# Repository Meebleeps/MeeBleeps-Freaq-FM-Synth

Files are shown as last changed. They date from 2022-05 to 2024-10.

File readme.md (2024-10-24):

# Meebleeps / Wirehead Freaq FM Synth
## Arduino Synth with Dual-voice 2-OP FM | Generative 2-track Polymetric Sequencer | Mozzi SDK

## NOTE This code is an open-source prototype and is not compatible with the Wirehead Instruments version of Freaq FM hardware
- Meebleeps was my personal project and was rebranded as Wirehead Instruments in 2023 to avoid brand confusion with MeeBlip - another completely separate synth design company.

An evolution of my first Mozzi synth build, this one features dual independent 2-operator FM voices paired with a 2-track generative sequencer.  

Each voice has independent carrier & modulator waveforms, FM ratio, modulation envelope & LFO.

Both tracks share the a single pattern (inspired by the Intellijel Metropolix) and can be stacked in unison or have different polymetric step-counts.  Track 1 can be offset 0-3 octaves above track 2 for separate bass & lead.

It started simple... but ended up cramming the 32K flash to the brim with features and wavetables, maxxing out the interface with obscure button combinations, and pushing the 16Mhz Arduino Nano to the edge!  Upside is it makes lots of funky noises now!

 #### Source Code:      https://github.com/Meebleeps/MeeBleeps-Freaq-FM-Synth
 #### Youtube Demo:     https://www.youtube.com/watch?v=KD6IrcmMkoA
 #### Youtube Channel:  https://www.youtube.com/channel/UC4I1ExnOpH_GjNtm7ZdWeWA

Source released under Creative Commons Attribution-NonCommercial-ShareAlike 4.0
Copyright (C) 2022 Meebleeps

***

## Important build-notes 

- My builds have used normally-closed switches, so the code assumes this.  09 May 2022: Added complier switches to handle normally-open switches
- This will probably compile to Arduino Uno, but it won't work properly without extensive modification as it uses all 8 of the Nano's analog input pins
- If you have issues with the compiled size not fitting in the Nano, this may be due to different compiler (I use VSCode & PlatformIO) or different bootloader in the Arduino (not sure which I have, but am compiling to Elegoo brand arduino nano). 
  - Check the compiler options in **MutantFMSynthOptions.h** to alter switch type or compile size
  - open the file MutantFMSynthOptions.h
  - find the line: `//#define COMPILE_SMALLER_BINARY`
  - uncomment the line so it looks like this:  `#define COMPILE_SMALLER_BINARY`
  - Then compile. It should now easily fit into the Nano.  This omits the semi-random wave tablesbut you probably won't miss it! :)
- Do not install the Mozzi library from PlatformIO in VSCode, it's outdated and will not build successfully. Instead, install its [latest git master branch](https://github.com/sensorium/Mozzi) to `lib/mozzi`. 
- The default settings target the Nano ATmega328 with the new bootloader. If you have avrdude errors during upload, you might have the old bootloader: change both instances of `nanoatmega328new` to `nanoatmega328` in `plaformio.ini`.

***

## Voices

-   2 independent FM voices
-   2-operator FM (for old-school prince of persia vibes! 😂)
-   Multi-mode FM ratios - quantised, free-multiple, independent
-   Multiple operator waveforms for carrier & modulator - Sine, Saw, Reverse Saw, Square, Noise, Off
-   Modulation level controlled by Attack/Decay envelope and LFO per-voice
-   Multiple LFO waveforms (same tables as the carrier oscillators) Sine, Saw, Reverse Saw, Square, Noise

## Sequencer

-   2/1.5 track polymetric sequencer with up to 16 steps per track (Both tracks use same note sequence but can have different step-counts for polymetric phasing)
-   Multiple generative algorithms - (semi)random notes, (semi)random runs, arpeggio, drone 
-   Sequence mutates/evolves at user-defined rate & note-density
-   Selectable tonic, octave & scale quantisation (Major, Minor, Pentatonic, Phrygian (GOA!), Octaves, Fifths)
-   Tap-tempo control
-   Sync input & output (Korg Volca compatible) 
-   16-step parameter-lock recording of synth parameters for track 1 (the Elektron way!)

## Hardware 
-   Arduino Nano (Elegoo) 
-   8x8 LED display with a MAX7219-based control board
-   Simple Mozzi output circuit 
-   Added power filtering caps on DC input and 5V rail
-   Designed to fit into Volca form factor 
-   Laser-cut metalisized acrylic faceplate 
-   Laser-cut wooden enclosure 
-   7V-12DC DC Power input 
-   Access to nano's USB port for firmware upgrades 

## Pins

These are the defaults defined for the faceplate controls:

| Pin | Function | Name in `MutantFMSynth.ino` |
|-----|---|---|
| A0  | Mutation | ANALOG_INPUT_MUTATION 
| A1  | Wobble | ANALOG_INPUT_LFO
| A2  | Population | ANALOG_INPUT_STEPCOUNT
| A3  | Attack | ANALOG_INPUT_MOD_ENVELOPE2 
| A4  | Lifespan | ANALOG_INPUT_DECAY
| A5  | Decay | ANALOG_INPUT_MOD_ENVELOPE1
| A6  | Ratio | ANALOG_INPUT_MOD_RATIO
| A7  | Depth | ANALOG_INPUT_MOD_AMOUNT 
| D3  | Start | BUTTON_INPUT_START
| D4  | Voice | BUTTON_INPUT_VOICE
| D5  | Rec | BUTTON_INPUT_REC
| D6  | Scales | BUTTON_INPUT_SCALE
| D10 | Func | BUTTON_INPUT_FUNC
| D12 | Tonic | BUTTON_INPUT_TONIC

## User Guide

### Buttons

-   Tonic - Select tonic through natural notes A - G
    -   [Func] + Tonic - Shift base octave from 0 - 5
    -   [Func][Rec] + Tonic - Select octave offset to Track 1 (track 1 & 2 can be 0-4 octaves apart)
-   Scales - Select current musical scale
    -   [Func] + Scales - Select current generative algorithm
    -   [Func][Rec] + Scales - Select the LFO waveform for the current voice 
-   Rec + knob - Hold down while moving a knob to record those parameters to the sequence 
    -   [Func][Rec] + knob - Hold down while moving a knob to delete the recorded sequence for that parameter 
    -   [Func][Rec] + buttons - Access various secondary functions
-   Start - Start or stop the sequencer
    -   [Func] + Start - Tap tempo
    -   [Func][Rec] + Start - Select the MODULATOR waveform for the current voice 
-   Voice - Select the active track which can be edited using the parameter inputs
    -   [Func] + Voice - Select the FM ratio mode for the current voice
    -   [Func][Rec] + Voice - Select CARRIER Waveform for the current voice 

### Rotary Inputs

-   Mutation - Adjust the likelihood that the sequence will change over time
    -   [Func] + Mutation - Adjust the liklihood that any given step will be a note or a rest
-   Population - Adjust the number of steps for the active track
    -   [Func] + Population - Adjust the number of steps for all tracks
-   Lifespan - Adjust the length of the notes (for all tracks)
-   Ratio - Select the carrier--to-modulator FM ratio (based on the current FM mode)
-   Wobble - Adjust the amount of LFO to apply to the modulator level for the active track
    -   [Func] + Wobble - Adjust the LFO rate for the active track
-   Attack - Adjust the attack time for the modulator level envelope
-   Decay - Adjust the decay time for the modulator level envelope
-   Depth - Adjust the amount of envelope to apply to the modulator level for the active track

## Issues / Limitations

-   Fair bit of jitter in the sequencer timing when tracking external sync due to somewhat naive approach to the 2-step-per-pulse volca sync 
-   Mozzi audio library has 10ms buffer 
-   The code is written for NORMALLY CLOSED switches - see latest updates in MutantFMSynth.ino updateButtonControls() for support for NORMALLY OPEN
-   The code may not fit in the Arduino Nano when compiled using the Arduino IDE or using different bootloaders

### Compiling on the Arduino IDE

If you have issues with the compiled size not fitting in the Nano, this may be due to different compiler (I use VSCode & PlatformIO) or different bootloader in the Arduino (not sure which I have, but am compiling to Elegoo brand arduino nano). 
- Check the compiler options in **MutantFMSynthOptions.h** to alter switch type or compile size
- open the file MutantFMSynthOptions.h
- find the line: //#define COMPILE_SMALLER_BINARY
- uncomment the line so it looks like this:  #define COMPILE_SMALLER_BINARY
- Then compile. It should now easily fit into the Nano.  This omits the semi-random wave tablesbut you probably won't miss it! :)

### Compiling in VSCode / PlatformIO

- Do not install the Mozzi library from PlatformIO in VSCode, it's outdated and will not build successfully. Instead, install its [latest git master branch](https://github.com/sensorium/Mozzi) to `lib/mozzi`. 
- The default settings target the Nano ATmega328 with the new bootloader. If you have avrdude errors during upload, you might have the old bootloader: change both instances of `nanoatmega328new` to `nanoatmega328` in `plaformio.ini`.

## Thanks

-   Inspired by Hagiwo's modular builds: https://www.youtube.com/channel/UCxErrnnVNEAAXPZvQFwobQw 
-   Mozzi audio library: https://sensorium.github.io/Mozzi/ 
-   Inkscape for vector graphics: https://inkscape.org/ 
-   Laser-cutting by Perth Creative Industries https://www.pcilasercutting.com.au/
-   Fritzing for circuit design: https://fritzing.org/ 
-   Great Scott for electronics tips! https://www.youtube.com/channel/UC6mIxFTvXkWQVEHPsEdflzQ

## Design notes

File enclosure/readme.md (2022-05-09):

Added awesome 3D printed enclosure files created by https://www.reddit.com/user/PollutionExpensive43/ - THANKS!

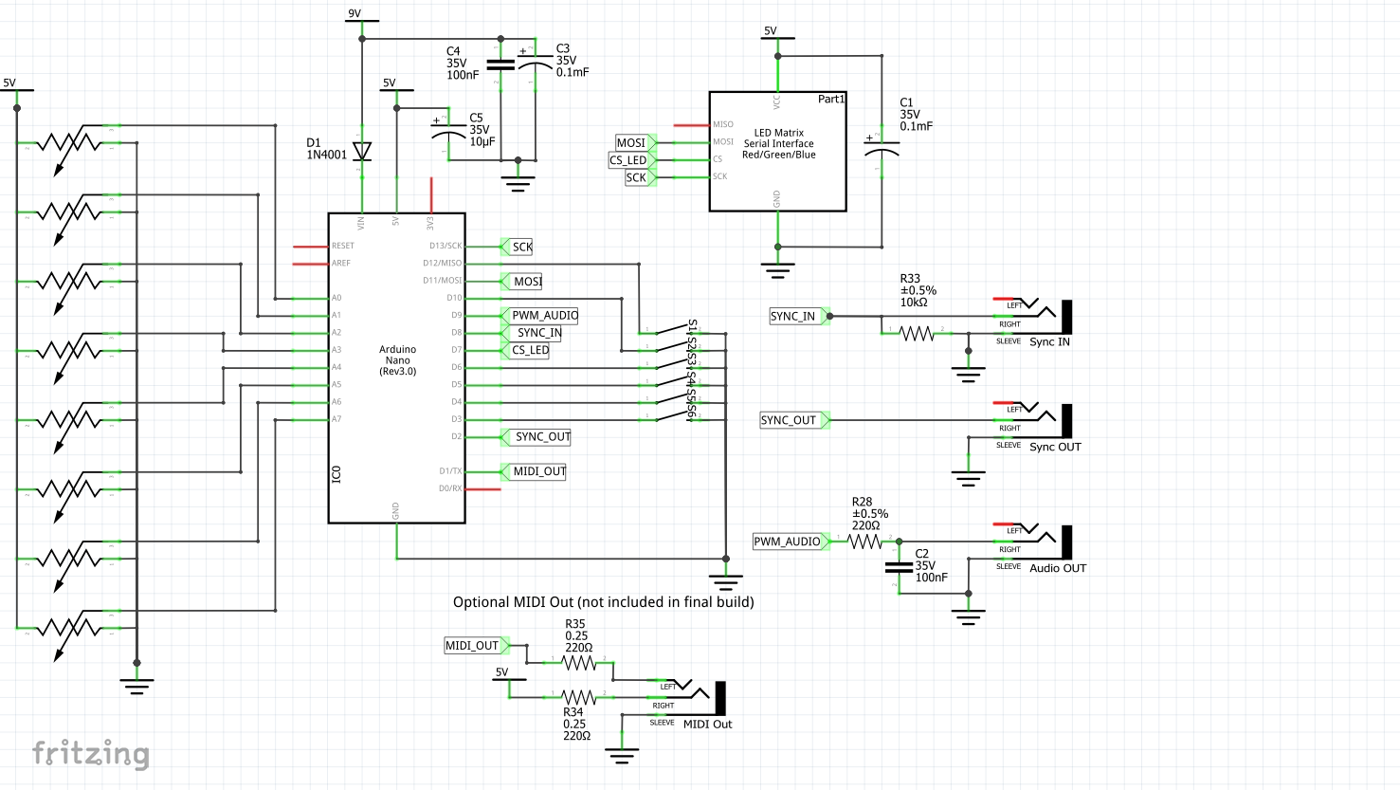
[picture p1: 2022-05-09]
MeeBleeps Freaq Schematic 26032022.png

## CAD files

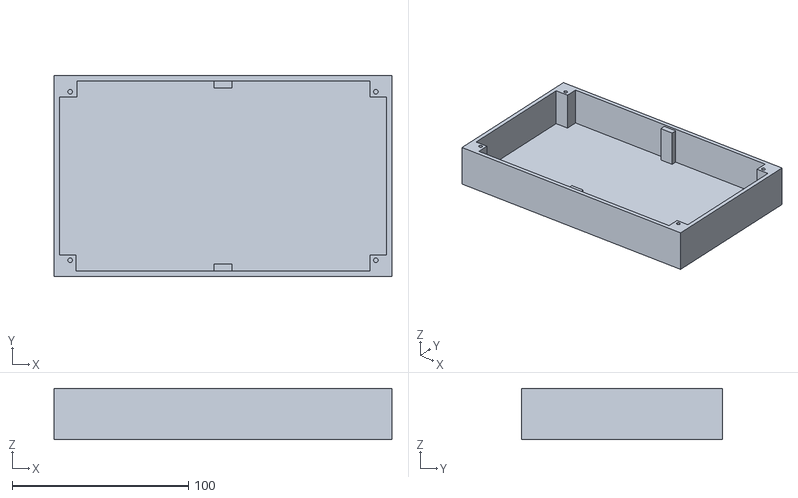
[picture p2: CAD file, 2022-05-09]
enclosure/Freaq Volca Case.stl
192.0 x 114.0 x 29.2

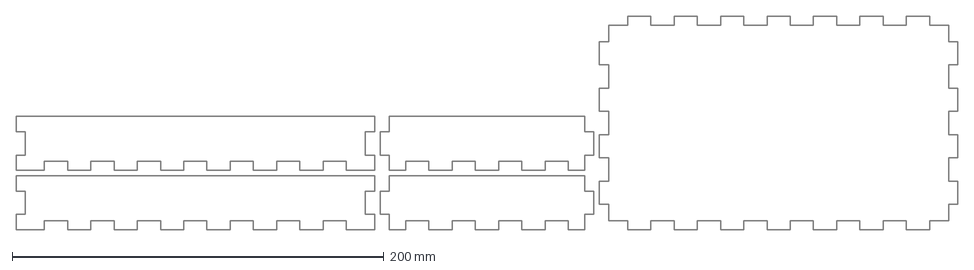
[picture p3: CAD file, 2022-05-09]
Mutant-Freaq Synth Box v1.0.dxf
507.0 x 115.0 mm

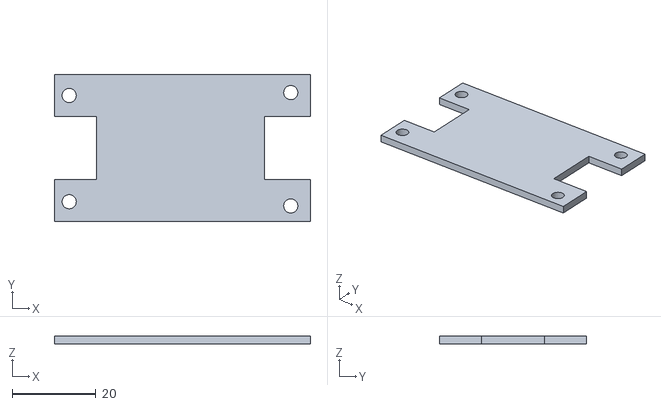
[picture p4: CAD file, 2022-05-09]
enclosure/LED Matrix Lid.stl
61.0 x 35.0 x 2.00

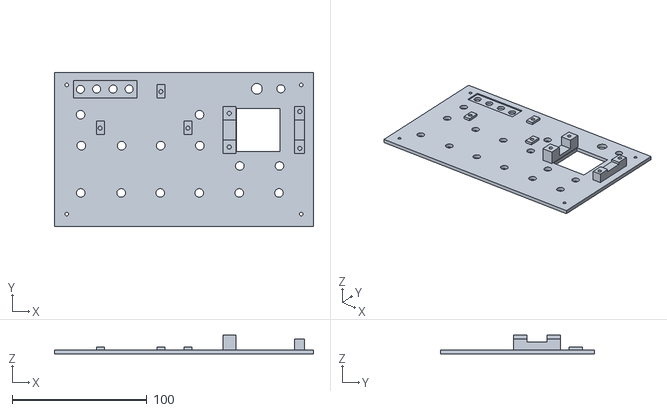
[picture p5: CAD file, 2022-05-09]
enclosure/Freaq Panel Latest.stl
192.0 x 114.0 x 14.0

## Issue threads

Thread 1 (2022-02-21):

I can't get this to compile for a Nano

s3r1al, 2022-02-21:
Arduino: 1.8.19 (Windows 10), Board: "Arduino Nano, ATmega328P"
C:\Users\dabar\Arduino\arduino-builder -dump-prefs -logger=machine -hardware C:\Users\dabar\Arduino\hardware -hardware C:\Users\dabar\AppData\Local\Arduino15\packages -tools C:\Users\dabar\Arduino\tools-builder -tools C:\Users\dabar\Arduino\hardware\tools\avr -tools C:\Users\dabar\AppData\Local\Arduino15\packages -built-in-libraries C:\Users\dabar\Arduino\libraries -libraries C:\Users\dabar\Documents\Arduino\libraries -fqbn=arduino:avr:nano:cpu=atmega328 -vid-pid=1A86_7523 -ide-version=10819 -build-path C:\Users\dabar\AppData\Local\Temp\arduino_build_624869 -warnings=none -build-cache C:\Users\dabar\AppData\Local\Temp\arduino_cache_776663 -prefs=build.warn_data_percentage=75 -prefs=runtime.tools.avrdude.path=C:\Users\dabar\Arduino\hardware\tools\avr -prefs=runtime.tools.avrdude-6.3.0-arduino17.path=C:\Users\dabar\Arduino\hardware\tools\avr -prefs=runtime.tools.arduinoOTA.path=C:\Users\dabar\Arduino\hardware\tools\avr -prefs=runtime.tools.arduinoOTA-1.3.0.path=C:\Users\dabar\Arduino\hardware\tools\avr -prefs=runtime.tools.avr-gcc.path=C:\Users\dabar\Arduino\hardware\tools\avr -prefs=runtime.tools.avr-gcc-7.3.0-atmel3.6.1-arduino7.path=C:\Users\dabar\Arduino\hardware\tools\avr -verbose C:\Users\dabar\Documents\Arduino\MeeBleeps-Freaq-FM-Synth-master\src\MutantFMSynth\MutantFMSynth.ino

C:\Users\dabar\Arduino\arduino-builder -compile -logger=machine -hardware C:\Users\dabar\Arduino\hardware -hardware C:\Users\dabar\AppData\Local\Arduino15\packages -tools C:\Users\dabar\Arduino\tools-builder -tools C:\Users\dabar\Arduino\hardware\tools\avr -tools C:\Users\dabar\AppData\Local\Arduino15\packages -built-in-libraries C:\Users\dabar\Arduino\libraries -libraries C:\Users\dabar\Documents\Arduino\libraries -fqbn=arduino:avr:nano:cpu=atmega328 -vid-pid=1A86_7523 -ide-version=10819 -build-path C:\Users\dabar\AppData\Local\Temp\arduino_build_624869 -warnings=none -build-cache C:\Users\dabar\AppData\Local\Temp\arduino_cache_776663 -prefs=build.warn_data_percentage=75 -prefs=runtime.tools.avrdude.path=C:\Users\dabar\Arduino\hardware\tools\avr -prefs=runtime.tools.avrdude-6.3.0-arduino17.path=C:\Users\dabar\Arduino\hardware\tools\avr -prefs=runtime.tools.arduinoOTA.path=C:\Users\dabar\Arduino\hardware\tools\avr -prefs=runtime.tools.arduinoOTA-1.3.0.path=C:\Users\dabar\Arduino\hardware\tools\avr -prefs=runtime.tools.avr-gcc.path=C:\Users\dabar\Arduino\hardware\tools\avr -prefs=runtime.tools.avr-gcc-7.3.0-atmel3.6.1-arduino7.path=C:\Users\dabar\Arduino\hardware\tools\avr -verbose C:\Users\dabar\Documents\Arduino\MeeBleeps-Freaq-FM-Synth-master\src\MutantFMSynth\MutantFMSynth.ino

Using board 'nano' from platform in folder: C:\Users\dabar\Arduino\hardware\arduino\avr

Using core 'arduino' from platform in folder: C:\Users\dabar\Arduino\hardware\arduino\avr

Detecting libraries used...

"C:\\Users\\dabar\\Arduino\\hardware\\tools\\avr/bin/avr-g++" -c -g -Os -w -std=gnu++11 -fpermissive -fno-exceptions -ffunction-sections -fdata-sections -fno-threadsafe-statics -Wno-error=narrowing -flto -w -x c++ -E -CC -mmcu=atmega328p -DF_CPU=16000000L -DARDUINO=10819 -DARDUINO_AVR_NANO -DARDUINO_ARCH_AVR "-IC:\\Users\\dabar\\Arduino\\hardware\\arduino\\avr\\cores\\arduino" "-IC:\\Users\\dabar\\Arduino\\hardware\\arduino\\avr\\variants\\eightanaloginputs" "C:\\Users\\dabar\\AppData\\Local\\Temp\\arduino_build_624869\\sketch\\MutantFMSynth.ino.cpp" -o nul

Alternatives for MozziGuts.h: [Mozzi-master@1.1.0]

ResolveLibrary(MozziGuts.h)

  -> candidates: [Mozzi-master@1.1.0]

"C:\\Users\\dabar\\Arduino\\hardware\\tools\\avr/bin/avr-g++" -c -g -Os -w -std=gnu++11 -fpermissive -fno-exceptions -ffunction-sections -fdata-sections -fno-threadsafe-statics -Wno-error=narrowing -flto -w -x c++ -E -CC -mmcu=atmega328p -DF_CPU=16000000L -DARDUINO=10819 -DARDUINO_AVR_NANO -DARDUINO_ARCH_AVR "-IC:\\Users\\dabar\\Arduino\\hardware\\arduino\\avr\\cores\\arduino" "-IC:\\Users\\dabar\\Arduino\\hardware\\arduino\\avr\\variants\\eightanaloginputs" "-IC:\\Users\\dabar\\Documents\\Arduino\\libraries\\Mozzi-master" "C:\\Users\\dabar\\AppData\\Local\\Temp\\arduino_build_624869\\sketch\\MutantFMSynth.ino.cpp" -o nul

Using cached library dependencies for file: C:\Users\dabar\AppData\Local\Temp\arduino_build_624869\sketch\LedMatrix.cpp

Alternatives for SPI.h: [SPI@1.0]

ResolveLibrary(SPI.h)

  -> candidates: [SPI@1.0]

Using cached library dependencies for file: C:\Users\dabar\AppData\Local\Temp\arduino_build_624869\sketch\avSequencer.cpp

Using cached library dependencies for file: C:\Users\dabar\AppData\Local\Temp\arduino_build_624869\sketch\avSequencerMultitrack.cpp

Using cached library dependencies for file: C:\Users\dabar\AppData\Local\Temp\arduino_build_624869\sketch\avSource.cpp

Using cached library dependencies for file: C:\Users\dabar\AppData\Local\Temp\arduino_build_624869\sketch\avSourceFM.cpp

Using cached library dependencies for file: C:\Users\dabar\Documents\Arduino\libraries\Mozzi-master\MozziGuts.cpp

Using cached library dependencies for file: C:\Users\dabar\Documents\Arduino\libraries\Mozzi-master\mozzi_analog.cpp

Using cached library dependencies for file: C:\Users\dabar\Documents\Arduino\libraries\Mozzi-master\mozzi_fixmath.cpp

Using cached library dependencies for file: C:\Users\dabar\Documents\Arduino\libraries\Mozzi-master\mozzi_midi.cpp

Using cached library dependencies for file: C:\Users\dabar\Documents\Arduino\libraries\Mozzi-master\mozzi_rand.cpp

Using cached library dependencies for file: C:\Users\dabar\Documents\Arduino\libraries\Mozzi-master\mozzi_utils.cpp

Using cached library dependencies for file: C:\Users\dabar\Documents\Arduino\libraries\Mozzi-master\twi_nonblock.cpp

Using cached library dependencies for file: C:\Users\dabar\Documents\Arduino\libraries\Mozzi-master\utility\FrequencyTimer2.cpp

Using cached library dependencies for file: C:\Users\dabar\Documents\Arduino\libraries\Mozzi-master\utility\TimerOne.cpp

Using cached library dependencies for file: C:\Users\dabar\Documents\Arduino\libraries\Mozzi-master\utility\TimerZero.cpp

Using cached library dependencies for file: C:\Users\dabar\Arduino\hardware\arduino\avr\libraries\SPI\src\SPI.cpp

Generating function prototypes...

"C:\\Users\\dabar\\Arduino\\hardware\\tools\\avr/bin/avr-g++" -c -g -Os -w -std=gnu++11 -fpermissive -fno-exceptions -ffunction-sections -fdata-sections -fno-threadsafe-statics -Wno-error=narrowing -flto -w -x c++ -E -CC -mmcu=atmega328p -DF_CPU=16000000L -DARDUINO=10819 -DARDUINO_AVR_NANO -DARDUINO_ARCH_AVR "-IC:\\Users\\dabar\\Arduino\\hardware\\arduino\\avr\\cores\\arduino" "-IC:\\Users\\dabar\\Arduino\\hardware\\arduino\\avr\\variants\\eightanaloginputs" "-IC:\\Users\\dabar\\Documents\\Arduino\\libraries\\Mozzi-master" "-IC:\\Users\\dabar\\Arduino\\hardware\\arduino\\avr\\libraries\\SPI\\src" "C:\\Users\\dabar\\AppData\\Local\\Temp\\arduino_build_624869\\sketch\\MutantFMSynth.ino.cpp" -o "C:\\Users\\dabar\\AppData\\Local\\Temp\\arduino_build_624869\\preproc\\ctags_target_for_gcc_minus_e.cpp"

"C:\\Users\\dabar\\Arduino\\tools-builder\\ctags\\5.8-arduino11/ctags" -u --language-force=c++ -f - --c++-kinds=svpf --fields=KSTtzns --line-directives "C:\\Users\\dabar\\AppData\\Local\\Temp\\arduino_build_624869\\preproc\\ctags_target_for_gcc_minus_e.cpp"

Compiling sketch...

"C:\\Users\\dabar\\Arduino\\hardware\\tools\\avr/bin/avr-g++" -c -g -Os -w -std=gnu++11 -fpermissive -fno-exceptions -ffunction-sections -fdata-sections -fno-threadsafe-statics -Wno-error=narrowing -MMD -flto -mmcu=atmega328p -DF_CPU=16000000L -DARDUINO=10819 -DARDUINO_AVR_NANO -DARDUINO_ARCH_AVR "-IC:\\Users\\dabar\\Arduino\\hardware\\arduino\\avr\\cores\\arduino" "-IC:\\Users\\dabar\\Arduino\\hardware\\arduino\\avr\\variants\\eightanaloginputs" "-IC:\\Users\\dabar\\Documents\\Arduino\\libraries\\Mozzi-master" "-IC:\\Users\\dabar\\Arduino\\hardware\\arduino\\avr\\libraries\\SPI\\src" "C:\\Users\\dabar\\AppData\\Local\\Temp\\arduino_build_624869\\sketch\\MutantFMSynth.ino.cpp" -o "C:\\Users\\dabar\\AppData\\Local\\Temp\\arduino_build_624869\\sketch\\MutantFMSynth.ino.cpp.o"

Using previously compiled file: C:\Users\dabar\AppData\Local\Temp\arduino_build_624869\sketch\LedMatrix.cpp.o

Using previously compiled file: C:\Users\dabar\AppData\Local\Temp\arduino_build_624869\sketch\avSequencer.cpp.o

Using previously compiled file: C:\Users\dabar\AppData\Local\Temp\arduino_build_624869\sketch\avSequencerMultitrack.cpp.o

Using previously compiled file: C:\Users\dabar\AppData\Local\Temp\arduino_build_624869\sketch\avSource.cpp.o

Using previously compiled file: C:\Users\dabar\AppData\Local\Temp\arduino_build_624869\sketch\avSourceFM.cpp.o

Compiling libraries...

Compiling library "Mozzi-master"

Using previously compiled file: C:\Users\dabar\AppData\Local\Temp\arduino_build_624869\libraries\Mozzi-master\mozzi_fixmath.cpp.o

Using previously compiled file: C:\Users\dabar\AppData\Local\Temp\arduino_build_624869\libraries\Mozzi-master\mozzi_utils.cpp.o

Using previously compiled file: C:\Users\dabar\AppData\Local\Temp\arduino_build_624869\libraries\Mozzi-master\mozzi_midi.cpp.o

Using previously compiled file: C:\Users\dabar\AppData\Local\Temp\arduino_build_624869\libraries\Mozzi-master\mozzi_rand.cpp.o

Using previously compiled file: C:\Users\dabar\AppData\Local\Temp\arduino_build_624869\libraries\Mozzi-master\twi_nonblock.cpp.o

Using previously compiled file: C:\Users\dabar\AppData\Local\Temp\arduino_build_624869\libraries\Mozzi-master\mozzi_analog.cpp.o

Using previously compiled file: C:\Users\dabar\AppData\Local\Temp\arduino_build_624869\libraries\Mozzi-master\MozziGuts.cpp.o

Using previously compiled file: C:\Users\dabar\AppData\Local\Temp\arduino_build_624869\libraries\Mozzi-master\utility\TimerOne.cpp.o

Using previously compiled file: C:\Users\dabar\AppData\Local\Temp\arduino_build_624869\libraries\Mozzi-master\utility\FrequencyTimer2.cpp.o

Using previously compiled file: C:\Users\dabar\AppData\Local\Temp\arduino_build_624869\libraries\Mozzi-master\utility\TimerZero.cpp.o

Compiling library "SPI"

Using previously compiled file: C:\Users\dabar\AppData\Local\Temp\arduino_build_624869\libraries\SPI\SPI.cpp.o

Compiling core...

Using precompiled core: C:\Users\dabar\AppData\Local\Temp\arduino_cache_776663\core\core_arduino_avr_nano_cpu_atmega328_df32d28809a1fa60758db8870d531b8c.a

Linking everything together...
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
Meebleeps, 2022-02-22:
Hi,

Thanks for reporting this. I have heard from a few people through youtube/reddit - its related to using different compilers (Arduino IDE vs VSCode*PlaformIO) and also different pre-installed bootloaders on different board manufacturers.

I am working on a fix I will release shortly to address these so it compiles on all platforms.  In the meantime, options that other builders have successfully used to get around this are:

* flash your nano with a different bootloader (eg optiloader)
* compile using VSCode - this is my dev environment and seems to generate smaller binaries
* remove one of the wavetables - they are 2KB each so removing one will make it fit easily.  the ramp waveform is probably the least useful in my experience playing he synth!

Cheers.

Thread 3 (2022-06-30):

Does it work on a UNO?

mayasfinest, 2022-06-30:
Hi,
excuse my little knowledge.
I also have problems with the size of the code but feel unable to figure out what to change to make it work on my side.
I used the standard Arduino Software trying to upload your code on a Nano compatible, no way.
But then I tried a UNO I had also lying around, the upload succeeded, just telling me "Low memory available, stability problems may occur."

Will it be possible to run the whole synth on a UNO instead and is there any change in pinout or behaviour...?
Or is it just fully compatible...?

Thanks for this gread project!
Cheers
Jörg

Meebleeps, 2022-07-01:
Hi Jörg,

You _can_ run it on the Uno, but the design uses the Nano's extra 2 Analog inputs, so you will not have control over the FM ratio and depth, so it won't be very good!  In theory it _could_ be redesigned but would take a lot of coding to assign secondary functions to other knobs and wouldn't be as fun to use.

To make it fit in the Nano, try this:

Open the file **MutantFMSynthOptions.h**

find the line:
`//#define COMPILE_SMALLER_BINARY`

now remove the commenting symbol **//** from the start so it looks like this:

`#define COMPILE_SMALLER_BINARY`

Then compile it.  It should now easily fit into the Nano by leaving out one of the wave tables - you will still have plenty to play with and probably won't miss it! :)

good luck!

mayasfinest, 2022-07-01:
Great, thanks!

The upload succeeded but I got a warning:

"Sketch uses 28938 bytes (94%) of program storage space. Maximum is 30720 bytes.
Global variables use 1778 bytes (86%) of dynamic memory, leaving 270 bytes for local variables. Maximum is 2048 bytes.
Low memory available, stability problems may occur."

I'll build the hardware now and see how it rocks, I'm excitied!

Meebleeps, 2022-07-01:
awesome, glad it worked.  yes that warning is normal - the code is designed not to use much local variable memory so it hasn't caused any issues (yet! 😁).

Good luck with the build - I'd love it if you shared video or pics when you've got it up and running! 😁 if you have any questions during the build, let me know and I'll try to help.

mayasfinest, 2022-07-01:
...is the Midi-Out fully implanted and working?
Does it  send all notes it produces out to channel1?
Can I change the channel somewhere in the code?

Thnx

mayasfinest, 2022-07-02:
Thanks mate for the extensive answer!

One last thing, on the schematic it says "0.1mF" at two posititons. I'd never seen this before.
At first I thought it was a type, meaning either 0.1nF or 0.1uF (micro), then realising it is a polarized cap.
Could you help me out, what do I need here...?

Thanks!

Meebleeps, 2022-07-03:
Hi, no worries. I used 100uF caps, which technically are 0.1mF but don’t know why fritzing displayed it like that!   the values were a bit trial and error - this was my second electronics project ever so self/YouTube-learning as I went!

____________________

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

mayasfinest, 2022-07-05:
This is what I did to your Synth!
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

Meebleeps, 2022-07-06:
I love it and I love the DOTT theme.  Awesome! 😁

Congratulations from Western Australia! 😊
____________________

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

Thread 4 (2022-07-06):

Permanant hiss in output

mayasfinest, 2022-07-06:
Me again,
i am getting a rather noticable but quite annoying med high frequency in my output (f#'').
When I decouple it with values bigger then 1uF it gets completely filtered out but the overall tone is too muffled.
Do you have any further ideas? Can you reproduce it? Where is the hiss produced....

PS: Doesn't make any difference if I run it from PSU or battery

Cheers,
Jörg

mayasfinest, 2022-07-06:
OK, i figured it out, in case anyone else also has this problem here's the solution:

I don't know why but the source of the hiss is the matrix display and to get rid of it i simply removed (!) the GND cable from the matrix-board, leaving just the 100uF between VCC+GND. The display is still fully functioning..

sergioska, 2023-05-15:
uhm ... same problem. I tried @mayasfinest solution but nothing ... it doesn't work, hiss doesn't go away.
I listen this background noise also in some videos on youtube, so I think that someone else has this problem
Does anyone find a solution?

sergioska, 2023-05-22:
Thanks @Meebleeps i'll try your suggestions!

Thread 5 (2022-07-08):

Testing the beast

spherical-sound-society, 2022-07-08:
Im building one, just in the test phase.

I have the arduino nano correctly flashed and connected just the audio output and the 8x8led matrix.

The switches are config as "normally open"

When I power it I get no leds on and just a faint background humm in the audio.

Should I simulate the press of any key to get it reacting? Im not sure if the led matrix is compatible and I dont feel like building the whole enchilada to later discover that the led matrix is not suitable.

This one uses the max7219 chip

If I manage to get it working I would love to try to update it for using a bluepill (wich is mozzi compatible too) so I can try to get way more voices and keep developing it.

But first lets go little by little!
Thanks!!

spherical-sound-society, 2022-07-08:
I have it connected like this, by the way:

clk>sck
miso>din
cs led>cs
gnd>gnd
vcc>vcc

Meebleeps, 2022-07-09:
Hi,

I am remote and don’t have decent internet access, so sorry I can’t help more. But I can confirm the led matrix uses a MAX7219 driver. The D_in pin on the Matrix should be connected to the arduino’s MOSI pin (Master Out Slave In).

____________________

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

spherical-sound-society, 2022-07-10:
Hi!
Yep, I had it right connected but I still get no sound or leds working.

No hurry about it, just reply when you come back from holydays :)

It is any thing that I can do for it to start working? Maybe it needs to press start or something?

Meebleeps, 2022-07-11:
Hi, when you power it on, the display should flash with a Meebleeps logo, so if that doesn’t happen, you have some problem with power, arduino, led matrix, or the connections between these.

If you get the logo but no sound, then it may be a problem with the audio output circuit or the button configuration. and yes maybe bash start a few times and see what happens 😊

____________________

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

spherical-sound-society, 2022-07-11:
Great. That´s exactly what I needed to know. I will try again.

Thanks!

spherical-sound-society, 2022-07-11:
Ok, it turns out that the cable was busted. I have tried with a dupons of mine instead the ones coming with the matrix and I have it working!! :D
Thank you so much!

Meebleeps, 2022-10-11:
Great to hear you got it working! 😊

____________________

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

Closed 2022-07-11.

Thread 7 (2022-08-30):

no audio

SimonePie, 2022-08-30:
Hi, congratulations on your super project ... a squeeze of Arduino!
As soon as I saw the video on YouTube I fell in love with it and of course I tried to make a prototype. Thanks to the Monitor function I have seen that the pots and buttons work correctly but I do not get any signal from pin D9 .... any suggestions?
Congratulations again for the project!

SimonePie, 2022-08-31:
Risolto!! ..errore mio!

Closed 2022-08-31.

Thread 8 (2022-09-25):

ARDUINO mega2560

Valgam91, 2022-09-25:
Is it possible to lode te scetch to a arduino Mega? I tested it but i could not uplode it("an error occured whileuploading the sketch" without more description)
Mozzi audio out is on pin 11 on the Mega.
Thx

Meebleeps, 2022-09-28:
Hi,

It should be possible, although I have not tested it myself.  Perhaps try uncommenting the flag  COMPILE_SMALLER_BINARY in MutantFMSynthOptions.h and see if that fixes it?

Cheers

__________________________________________________________

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

Hans0lo, 2023-02-04:
Hi @Valgam91,
I also tried uploading to a Mega and also had issues uploading.
```
```

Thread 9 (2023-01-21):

Potentiometer values missing?

n9jcv, 2023-01-21:
I dont see the potentiometer valus on the schematic.  Did I miss?  What value are they?

Meebleeps, 2023-01-21:
Hi,I used 10k linear pots. I believe you can use between 5k-50k and they will work just fine. Cheers. ____________________On 21 Jan 2023, at 2:16 pm, n9jcv ***@***.***> wrote:
I dont see the potentiometer valus on the schematic.  Did I miss?  What value are they?

—Reply to this email directly, view it on GitHub, or unsubscribe.You are receiving this because you are subscribed to this thread.Message ID: ***@***.***>

Closed 2023-01-31.

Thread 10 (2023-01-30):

cant successfully change Display Orientation

Hans0lo, 2023-01-30:
Hi,
I built the Freaq myself using a Nano, and a LED matrix breakout board (max7219 based).

Since I read in your source that there is an option to change orientation, I started my build without testing the diplay before mounting it on my faceplate.

I am using the pins exactly as in your source - however, the display is reversed upside down...
I tried to change the function 'void initialiseDisplay()' in 'MutantFMSynth.ino' from:
```
void initialiseDisplay()
{
  ledDisplay.initialise();
  ledDisplay.setOrientation(LEDMATRIX_ORIENTATION_0);
...
```
to:
```
void initialiseDisplay()
{
  ledDisplay.initialise();
  ledDisplay.setOrientation(LEDMATRIX_ORIENTATION_180);
...
```
but no change.

I also tried changing the setOrientation line in 'void LedMatrix::initialise()' from 'setOrientation(LEDMATRIX_ORIENTATION_0);'
to 'setOrientation(LEDMATRIX_ORIENTATION_180);'

also not change.

I tried with both set to 180 and with only one of each, but no matter what i do, the display is always upside down...
the orientation options dont change the actual orientation at all.

any tips for me what I could do in the software to make the display change orientation?
(I would like to avoid turning the hardware, as that would cause issue with my faceplate...)

Meebleeps, 2023-01-31:
Yes sorry - that code was a stub! I never ended up completing the different orientations as I settled on a hardware layout which didn't require it.

Here are some updated functions for LedMatrix.cpp which add support for a 180degree flip.  I don't really want to do 90/270! :)  You only need to amend setPixel(), togglePixel() and setRowPixels().  the other functions like displayIcon reuse these functions so once they are fixed it all works (just tested now on my prototype)

/*----------------------------------------------------------------------------------------------------------
 * setPixel
 * was almost correct - flips the X axis but needs to check for orientation and if required, invert the Y parameter
  *----------------------------------------------------------------------------------------------------------
 */
void LedMatrix::setPixel(uint8_t x, uint8_t y, uint8_t value)
{
  if (orientation == LEDMATRIX_ORIENTATION_180)
  {
    y = (LEDMATRIX_MAXROWS - 1) - y;
  }

  if (x < LEDMATRIX_MAXCOLS && y < LEDMATRIX_MAXROWS)
  {
    if (value)
    {
      vRAM[y] = vRAM[y] | displayBit[x];
    }
    else
    {
      vRAM[y] = vRAM[y] & ~displayBit[x];
    }

    rowModified |= 1 << y;
  }
}

/*----------------------------------------------------------------------------------------------------------
 * togglePixel
 * same issue
 *----------------------------------------------------------------------------------------------------------
 */
void LedMatrix::togglePixel(uint8_t x, uint8_t y)
{
  if (orientation == LEDMATRIX_ORIENTATION_180)
  {
    y = (LEDMATRIX_MAXROWS - 1) - y;
  }

  if (y < LEDMATRIX_MAXROWS && x < LEDMATRIX_MAXCOLS)
  {
    // if pixel is on, switch off
    if (vRAM[y] & displayBit[x])
    {
      vRAM[y] = vRAM[y] & ~displayBit[x];
    }
    else
    {
      vRAM[y] = vRAM[y] | displayBit[x];
    }

    rowModified |= 1 << y;
  }
}

/*----------------------------------------------------------------------------------------------------------
 * setRowPixels
 * add a check for orientation and if == 180 invert the y parameter as above.  then rather than copying the bits as-is from the given value, reverse the bitfield
 *----------------------------------------------------------------------------------------------------------
 */
void LedMatrix::setRowPixels(uint8_t y, uint8_t value)
{
  if (y < LEDMATRIX_MAXROWS)
  {
    if (orientation == LEDMATRIX_ORIENTATION_180)
    {
      uint8_t reversedValue = 0;

      y = (LEDMATRIX_MAXROWS - 1) - y;

      for (int i = 0; i < 8; ++i)
      {
        reversedValue <<= 1;
        reversedValue |= (value & 0x01);
        value >>= 1;
      }

      vRAM[y] = reversedValue;
      rowModified |= 1 << y;
    }
    else
    {
      vRAM[y] = value;
      rowModified |= 1 << y;
    }
  }

}

Meebleeps, 2023-01-31:
As an aside, it was pretty inefficient (and dumb) of me to do this check at runtime, as the orientation of the matrix isn't likely to change unless you design some sort of symmetrical handheld with an accelerometer!  hmmm.. that would be cool... 😁

So orientation should really be a precompiler flag and use something like:

~~~
#define LED_ORIENTATION 180

...

#if LED_ORIENTATION == 180

// 180 flip version
...

#elif LED_ORIENTATION == 0

// standard version
...

#endif

Hans0lo, 2023-01-31:
Hey - thnx for the speedy reply and the code fix!
will test it ASAP and report back ::

Hans0lo, 2023-01-31:
worked like a charm!

Meebleeps, 2023-01-31:
Awesome - much better than reworking the entire enclosure!!  when you're finished I would love to see (& hear) your build!

Closed 2023-01-31.

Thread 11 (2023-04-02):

About the power supply

renzodus, 2023-04-02:
Hi! I'm planning on building this beast, and I was wandering if it'd be possible to use only the nano's usb port for powering. Would it be enough? In that case I guess I can omit this part of the circuit, am I right?
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

Meebleeps, 2023-04-02:
Hi, thanks! yes you can power it direct from usb - delete c3, c5 & d1. But keep c5 to filter the 5v rail.  Would be great to see your build when you're done! 😊

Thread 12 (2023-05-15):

Cant compile

RakouskyS, 2023-05-15:
Hey, im trying to get this loaded on my Nano Clone / ATMega328

When compiling I get this error

```
Processing nanoatmega328new (platform: atmelavr; board: nanoatmega328new; framework: arduino)
---------------------------------------------------------------------------------------------------------------------------------------------------------------------------------------------------------------------------------
Verbose mode can be enabled via `-v, --verbose` option
CONFIGURATION: https://docs.platformio.org/page/boards/atmelavr/nanoatmega328new.html
PLATFORM: Atmel AVR (4.1.0) > Arduino Nano ATmega328 (New Bootloader)
HARDWARE: ATMEGA328P 16MHz, 2KB RAM, 30KB Flash
DEBUG: Current (avr-stub) External (avr-stub, simavr)
PACKAGES:
 - framework-arduino-avr @ 5.1.0
 - toolchain-atmelavr @ 1.70300.191015 (7.3.0)
Converting MutantFMSynth.ino
LDF: Library Dependency Finder -> https://bit.ly/configure-pio-ldf
LDF Modes: Finder ~ chain, Compatibility ~ soft
Found 7 compatible libraries
Scanning dependencies...
Dependency Graph
|-- Mozzi @ 1.1.0
|-- SPI @ 1.0
Building in debug mode
Compiling .pio\build\nanoatmega328new\src\LedMatrix.cpp.o
Compiling .pio\build\nanoatmega328new\src\avSequencer.cpp.o
Compiling .pio\build\nanoatmega328new\src\avSequencerMultitrack.cpp.o
Compiling .pio\build\nanoatmega328new\src\avSource.cpp.o
Compiling .pio\build\nanoatmega328new\src\avSourceFM.cpp.o
Compiling .pio\build\nanoatmega328new\lib016\Mozzi\MozziGuts.cpp.o
Compiling .pio\build\nanoatmega328new\lib016\Mozzi\mozzi_analog.cpp.o
Compiling .pio\build\nanoatmega328new\lib016\Mozzi\mozzi_fixmath.cpp.o
Compiling .pio\build\nanoatmega328new\lib016\Mozzi\mozzi_midi.cpp.o
Compiling .pio\build\nanoatmega328new\lib016\Mozzi\mozzi_rand.cpp.o
Compiling .pio\build\nanoatmega328new\lib016\Mozzi\mozzi_utils.cpp.o
Compiling .pio\build\nanoatmega328new\lib016\Mozzi\twi_nonblock.cpp.o
Compiling .pio\build\nanoatmega328new\lib016\Mozzi\utility\FrequencyTimer2.cpp.o
In file included from src\avSource.h:31:0,
                 from src\avSource.cpp:12:
C:\Users\rakou\Documents\Arduino\libraries\Mozzi/LowPassFilter.h:17:2: warning: #warning This header is deprecated, please use ResonantFilter.h instead. [-Wcpp]
 #warning This header is deprecated, please use ResonantFilter.h instead.
  ^~~~~~~
Compiling .pio\build\nanoatmega328new\lib016\Mozzi\utility\TimerOne.cpp.o
src\avSequencerMultitrack.cpp: In member function 'void MutatingSequencerMultiTrack::nextStep(bool)':
src\avSequencerMultitrack.cpp:76:74: warning: operation on '((MutatingSequencerMultiTrack*)this)->MutatingSequencerMultiTrack::currentTrackStep[((int)i)]' may be undefined [-Wsequence-point]
     for (uint8_t i=0; i < MAX_SEQUENCER_TRACKS; i++) currentTrackStep[i] = ++currentTrackStep[i] % trackSequenceLength[i];
                                                      ~~~~~~~~~~~~~~~~~~~Compiling .pio\build\nanoatmega328new\lib016\Mozzi\utility\TimerZero.cpp.o
~^~~Compiling .pio\build\nanoatmega328new\libb12\SPI\SPI.cpp.o
~~~~~~~~~~~~~~~~~~~~~~~~~~~~~~~~~~~~~~~~~~~~~
In file included from src\avSource.h:31:0,
                 from src\avSourceFM.cpp:24:
C:\Users\rakou\Documents\Arduino\libraries\Mozzi/LowPassFilter.h:17:2: warning: #warning This header is deprecated, please use ResonantFilter.h instead. [-Wcpp]
 #warning This header is deprecated, please use ResonantFilter.h instead.
  ^~~~~~~
Archiving .pio\build\nanoatmega328new\libFrameworkArduinoVariant.a
Compiling .pio\build\nanoatmega328new\FrameworkArduino\CDC.cpp.o
Compiling .pio\build\nanoatmega328new\FrameworkArduino\HardwareSerial.cpp.o
Compiling .pio\build\nanoatmega328new\FrameworkArduino\HardwareSerial0.cpp.o
Compiling .pio\build\nanoatmega328new\FrameworkArduino\HardwareSerial1.cpp.o
Compiling .pio\build\nanoatmega328new\FrameworkArduino\HardwareSerial2.cpp.o
Compiling .pio\build\nanoatmega328new\FrameworkArduino\HardwareSerial3.cpp.o
Compiling .pio\build\nanoatmega328new\FrameworkArduino\IPAddress.cpp.o
Compiling .pio\build\nanoatmega328new\FrameworkArduino\PluggableUSB.cpp.o
Compiling .pio\build\nanoatmega328new\FrameworkArduino\Print.cpp.o
Compiling .pio\build\nanoatmega328new\FrameworkArduino\Stream.cpp.o
Compiling .pio\build\nanoatmega328new\FrameworkArduino\Tone.cpp.o
Archiving .pio\build\nanoatmega328new\lib016\libMozzi.a
Archiving .pio\build\nanoatmega328new\libb12\libSPI.a
Compiling .pio\build\nanoatmega328new\FrameworkArduino\USBCore.cpp.o
Compiling .pio\build\nanoatmega328new\FrameworkArduino\WInterrupts.c.o
Compiling .pio\build\nanoatmega328new\FrameworkArduino\WMath.cpp.o
Compiling .pio\build\nanoatmega328new\FrameworkArduino\WString.cpp.o
Compiling .pio\build\nanoatmega328new\FrameworkArduino\abi.cpp.o
Compiling .pio\build\nanoatmega328new\FrameworkArduino\hooks.c.o
Compiling .pio\build\nanoatmega328new\FrameworkArduino\main.cpp.o
Compiling .pio\build\nanoatmega328new\FrameworkArduino\new.cpp.o
Compiling .pio\build\nanoatmega328new\FrameworkArduino\wiring.c.o
Compiling .pio\build\nanoatmega328new\FrameworkArduino\wiring_analog.c.o
Compiling .pio\build\nanoatmega328new\FrameworkArduino\wiring_digital.c.o
Compiling .pio\build\nanoatmega328new\FrameworkArduino\wiring_pulse.S.o
Compiling .pio\build\nanoatmega328new\FrameworkArduino\wiring_pulse.c.o
Compiling .pio\build\nanoatmega328new\FrameworkArduino\wiring_shift.c.o
Archiving .pio\build\nanoatmega328new\libFrameworkArduino.a
Linking .pio\build\nanoatmega328new\firmware.elf
C:\Users\rakou\AppData\Local\Temp\ccyMnhVP.ltrans0.ltrans.o: In function `main':
C:\Users\rakou\.platformio\packages\framework-arduino-avr\cores\arduino/main.cpp:43: undefined reference to `setup'
C:\Users\rakou\.platformio\packages\framework-arduino-avr\cores\arduino/main.cpp:46: undefined reference to `loop'
collect2.exe: error: ld returned 1 exit status
*** [.pio\build\nanoatmega328new\firmware.elf] Error 1
```

I've tried the other bootloader but it still doesnt compile for me..

RakouskyS, 2023-05-18:
I now get the error

`C:\Users\rakou\Documents\MeeBleeps-Freaq-FM-Synth-master/src/avSource.cpp:16: undefined reference to `vtable for MutatingSource'`

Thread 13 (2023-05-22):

User manual?

sergioska, 2023-05-22:
Is there any user documentation?
Of course, many functions can be discovered by using the device and seeing youtube videos, but it should be great to get detailed documentation on all the functions and how to use them.

Meebleeps, 2023-05-22:
Hi there,

There isn't specific user documentation for this version, however the retail version has a comprehensive manual here: https://meebleeps.com/support

There are a number of differences between the open-source prototype and the retail firmware but it should get you started. 👍

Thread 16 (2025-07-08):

Func button reseting the arduino

ManuMontesino, 2025-07-08:
Hi, im building the synth, by the way, nice project :), i already achieve to get some audio, but when i press the func button (connected to pin D10), the led matrix brights down and the arduino resets, im using decoupling caps, following the schematic, and i changed the definition in the code for normal open switches, but it keeps shuting down, any advise?, other problem is that when i start the sequencer it makes random noises, and doesnt respond to the buttons o pots

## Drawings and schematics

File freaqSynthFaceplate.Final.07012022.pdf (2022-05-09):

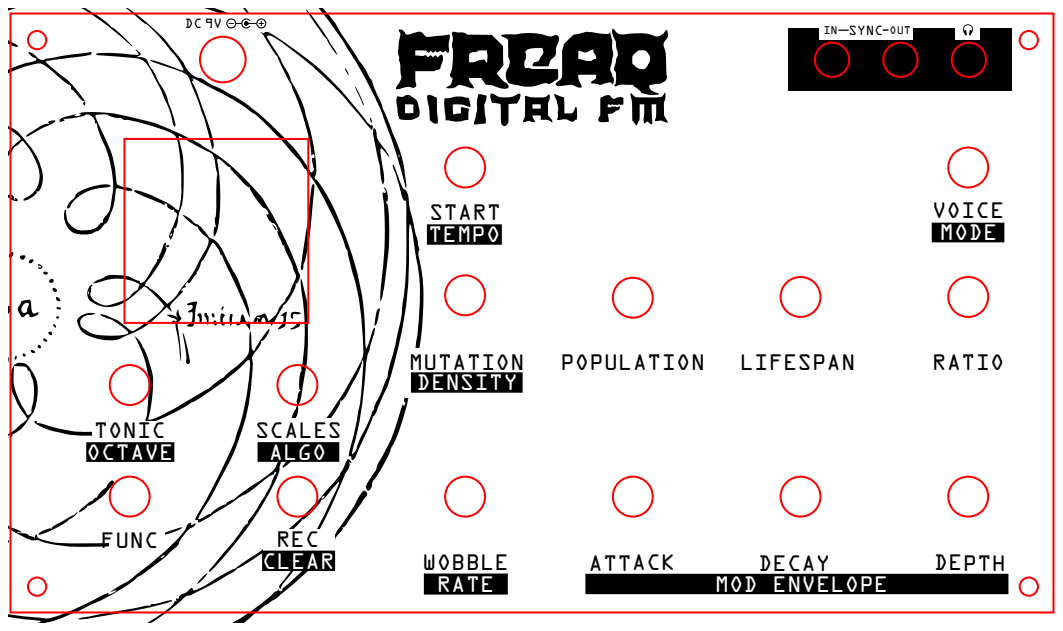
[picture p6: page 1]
FUNC; TONIC; SCALES; START; REC; VOICE; DENSITY; RATE; MOD ENVELOPE; IN SYNC OUT; ALGO; MODE; OCTAVE; TEMPO; CLEAR; LIFESPAN; RATIO; WOBBLE; ATTACK; DECAY; MUTATION; POPULATION; DEPTH

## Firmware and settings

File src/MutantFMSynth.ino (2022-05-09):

/*----------------------------------------------------------------------------------------------------------
 * MutantFMSynth.ino
 * 
 * Main project file for the Mutant FM Synth. 
 * 
 * Instantiates all mutant class objects 
 * Calls the Mozzi audio hook functions
 * manages the user interface
 * 
 * Source Code Repository:  https://github.com/Meebleeps/MeeBleeps-Freaq-FM-Synth
 * Youtube Channel:         https://www.youtube.com/channel/UC4I1ExnOpH_GjNtm7ZdWeWA
 * 
 * (C) 2021-2022 Meebleeps
*-----------------------------------------------------------------------------------------------------------
*/

#include <Arduino.h>
#include <MozziGuts.h>
#include <mozzi_rand.h>
#include <EventDelay.h>


#include "avSource.h"
#include "avSequencerMultiTrack.h"
#include "avMidi.h"
#include "LedMatrix.h"
#include "mutantBitmaps.h"
#include <avr/pgmspace.h>

#include "MutantFMSynthOptions.h"

// define the pins
#define PIN_SYNC_IN       8
#define PIN_SYNC_OUT      2
#define TIMER_SYNC_PULSE_OUTPUT_MILLIS 15

#define PIN_AUDIO_OUT     9
#define PIN_BUTTON0       4
#define PIN_BUTTON1       5
#define PIN_BUTTON2       6
#define PIN_BUTTON3       3
#define PIN_BUTTON4       10
#define PIN_BUTTON5       12
#define MAX_BUTTON_INPUTS 6

#define SEQUENCER_TRACK_0   0
#define SEQUENCER_TRACK_1   1
#define SEQUENCER_TRACK_0_DISPLAY_ROW_0   4
#define SEQUENCER_TRACK_0_DISPLAY_ROW_1   5
#define SEQUENCER_TRACK_1_DISPLAY_ROW_0   6
#define SEQUENCER_TRACK_1_DISPLAY_ROW_1   7
#define LFO_TRACK_0_DISPLAY_ROW           2
#define LFO_TRACK_1_DISPLAY_ROW           2
#define TRIGGER_DISPLAY_ROW               0
#define TRIGGER_DISPLAY_COL               7
#define CURRENT_VOICE_DISPLAY_ROW         1

#define MAX_ANALOG_INPUTS               8
#define MAX_ANALOG_VALUE                1023

#define ANALOG_INPUT_MOD_AMOUNT         7
#define ANALOG_INPUT_DECAY              4
#define ANALOG_INPUT_MUTATION           0
#define ANALOG_INPUT_LFO                1
#define ANALOG_INPUT_MOD_RATIO          6
#define ANALOG_INPUT_STEPCOUNT          2
#define ANALOG_INPUT_MOD_ENVELOPE1      5
#define ANALOG_INPUT_MOD_ENVELOPE2      3

#define ANALOG_INPUT_MOVEMENT_THRESHOLD 5

// listed in order of left to right.
#define BUTTON_INPUT_FUNC   4
#define BUTTON_INPUT_TONIC  5
#define BUTTON_INPUT_SCALE  2
#define BUTTON_INPUT_START  3
#define BUTTON_INPUT_REC    1
#define BUTTON_INPUT_VOICE  0
#define MAX_OSCILLATOR_MODES 1

#define INTERFACE_MODE_NORMAL 0
#define INTERFACE_MODE_SHIFT  1

#define DISPLAY_SETTING_CHANGE_PERSIST_MILLIS 350
#define DISPLAY_SETTING_INTENSITY 4

#define MOTION_RECORD_NONE  0
#define MOTION_RECORD_REC   1
#define MOTION_RECORD_CLEAR 2

// MOZZI variables
// original had at 256 but as CPU got tight had to reduce it
// needs to be at least 128. 64Hz means incoming sync pulses are regularly missed between updates.
#define CONTROL_RATE 128   

// todo:  decrease INTERFACE_UPDATE_DIVIDER  if controls are externally modulated via CV voltage inputs
#define INTERFACE_UPDATE_DIVIDER_ANALOG 5
#define INTERFACE_UPDATE_DIVIDER_DIGITAL 7
#define INTERFACE_UPDATE_DIVIDER_LFO 2
#define INTERFACE_UPDATE_DIVIDER_DISPLAY 32


byte firstTimeStart = true;
byte iTrigger = 1;      
byte iLastTrigger = 0;
byte interfaceMode    = INTERFACE_MODE_NORMAL;
byte controlSynthVoice = 0;
byte motionRecordMode = MOTION_RECORD_NONE;

int iLastAnalogValue[MAX_ANALOG_INPUTS]    = {0,0,0,0,0,0,0,0};
int iCurrentAnalogValue[MAX_ANALOG_INPUTS] = {0,0,0,0,0,0,0,0};

// save space for digital inputs - use a bit rather than a byte per button 
uint8_t bitsLastButton;

// save space for digital inputs - use a bit rather than a byte per button 
uint8_t bitsCurrentButton;

// save space for param lock flags - use a bit rather than a byte per param 
uint8_t bitsLastParamLock;

// time since the last updateAudio()
uint32_t lastUpdateMicros;

// used to divide the calls to updateControl to spread out control reads and save cpu cycles 
uint8_t updateCounter = 0;




// voice 1 instance
MutatingFM          voice0;

// voice 2 instance
MutatingFM          voice1;

// array of pointers to the MutatingFM instances to simplfy the code
MutatingFM*         voices[2];  

// MAX7219 display matrix interface class
LedMatrix           ledDisplay;

// timer to pull sync output low at end of pulse
EventDelay          syncOutputTimer;

// timer to prevent update of the display while a settings icon is being displayed
EventDelay          settingDisplayTimer;

// the sequencer
MutatingSequencerMultiTrack sequencer;





/*----------------------------------------------------------------------------------------------------------
 * setup()
 *----------------------------------------------------------------------------------------------------------
 */
void setup() 
{
  #ifdef ENABLE_MIDI_OUTPUT
  Serial.begin(31250);
  #else
  Serial.begin(115200);
  Serial.print(F("\n\n\n\n\n-----------------------------------------------------------------------\n"));
  Serial.print(F("Freaq - Mozzi-based Mutating FM Synth.   Build "));
  Serial.print  (__DATE__);
  Serial.print  (F(" "));
  Serial.println  (__TIME__);
  #endif

  initialisePins();
  initialiseDisplay();
  initialiseSources();
  initialiseSequencer();
  
  startMozzi(CONTROL_RATE);
}


/*----------------------------------------------------------------------------------------------------------
 * debugPrintMemoryUsage
 * does nothing now.  used while optimising memory usage 
 *----------------------------------------------------------------------------------------------------------
 */
void debugPrintMemoryUsage()
{
/*
  debugWriteValue("sizeof(synthVoice)", sizeof(synthVoice));
  debugWriteValue("sizeof(sequencer)", sizeof(sequencer));
*/  

}


/*----------------------------------------------------------------------------------------------------------
 * initialiseDisplay
 *----------------------------------------------------------------------------------------------------------
 */
void initialiseDisplay()
{
  ledDisplay.initialise();
  ledDisplay.setOrientation(LEDMATRIX_ORIENTATION_0);
  
  settingDisplayTimer.start(0);

  
  // display logo
  for (uint8_t i = 10; i < 100; i += 10)
  {
    ledDisplay.clearScreen();
    delay(i);
    displaySettingIcon(BITMAP_MEEBLEEPS);
    delay(i);
  }
  
  //fade logo to target intensity
  for(int i = 15; i>= DISPLAY_SETTING_INTENSITY; i--)
  {
    ledDisplay.setIntensity(i);

    delay(20);
  }
  
//  ledDisplay.setIntensity(DISPLAY_SETTING_INTENSITY);
//  displaySettingIcon(BITMAP_MEEBLEEPS);

  #ifndef ENABLE_MIDI_OUTPUT
  Serial.println(F("initialiseDisplay() complete"));
  #endif
}




/*----------------------------------------------------------------------------------------------------------
 * initialisePins
 *----------------------------------------------------------------------------------------------------------
 */
void initialisePins()
{
  #ifndef ENABLE_MIDI_OUTPUT
  Serial.println(F("initialisePins()"));
  #endif

  pinMode(PIN_SYNC_IN, INPUT);          // sync is pulled down by external pulldown resistor
  pinMode(PIN_SYNC_OUT, OUTPUT);
  pinMode(PIN_BUTTON0, INPUT_PULLUP);   // all other buttons are pulled up by internal pullup resistor
  pinMode(PIN_BUTTON1, INPUT_PULLUP);
  pinMode(PIN_BUTTON2, INPUT_PULLUP);
  pinMode(PIN_BUTTON3, INPUT_PULLUP);
  pinMode(PIN_BUTTON4, INPUT_PULLUP);
  pinMode(PIN_BUTTON5, INPUT_PULLUP);

  pinMode(A0, INPUT);
  pinMode(A1, INPUT);
  pinMode(A2, INPUT);
  pinMode(A3, INPUT);
  pinMode(A4, INPUT);
  pinMode(A5, INPUT); 
  pinMode(A6, INPUT);
  pinMode(A7, INPUT); 

  // initialise 
  bitsLastButton    = 0;
  bitsCurrentButton = 0;

  for (uint8_t i = 0; i < MAX_ANALOG_INPUTS; i++)
  {
    iLastAnalogValue[i]    = 0;
  }
}



/*----------------------------------------------------------------------------------------------------------
 * initialiseSources
 *----------------------------------------------------------------------------------------------------------
 */
void initialiseSources()
{
  voice0.setOscillator(0);
  voice1.setOscillator(1);

  voices[0] = &voice0;  
  voices[1] = &voice1;  
}



/*----------------------------------------------------------------------------------------------------------
 * initialiseSequencer
 *----------------------------------------------------------------------------------------------------------
 */
void initialiseSequencer()
{
  sequencer.setScale(SCALEMODE_MINOR);
  sequencer.newSequence(16);
}




/*----------------------------------------------------------------------------------------------------------
 * updateControl
 * called by Mozzi Library on CONTROL_RATE frequency
 * spreads out control logic updates so that we don't bog down the CPU
 *
 * every step - check for sync trigger and update sequencer
 * if this gets delayed, note on/off commands will drift
 *----------------------------------------------------------------------------------------------------------
 */
void updateControl()
{
  uint8_t doDisplayUpdate = false;

  lastUpdateMicros = micros();
  updateCounter++;



  // check for incoming sync trigger and if necessary update output sync
  // do every update to ensure minimum sync jitter 
  updateSyncTrigger();

  // update sequencer returns true if the sequencer has moved to next step
  if (updateSequencer())
  {

    // check to see if sequencer should update the output sync pulse
    if (sequencer.outputSyncPulse())
    {
      outputSyncPulse();
    }

    //update the display once per sequencer step   
    // but do the display update at the end of updateControl so that any latency is introduced after all critical functions are processed

    doDisplayUpdate = true; 
  }
  // check controls once every INTERFACE_UPDATE_DIVIDER steps for efficiency
  // don't update these if the sequencer has updated as that is expensive
  else if(updateCounter % INTERFACE_UPDATE_DIVIDER_ANALOG == 0)
  {
    // now check analog controls
    updateAnalogControls();
  
  }
  // never check both analog and digital controls in the same step to causing buffer underflows
  else if(updateCounter % INTERFACE_UPDATE_DIVIDER_DIGITAL == 0)
  {
    // check button controls first to ensure interface mode is correctly set
    updateButtonControls();

  }
  else if(updateCounter % INTERFACE_UPDATE_DIVIDER_LFO == 0)
  {
    //update display of LFO modulation at higher rate than rest of display
    updateLFOModulationDisplay();
  }
  else 
  {
    doDisplayUpdate = (updateCounter % INTERFACE_UPDATE_DIVIDER_DISPLAY == 0);
  }

  #ifndef ENABLE_MIDI_OUTPUT
  //Serial.print(micros() - lastUpdateMicros);
  //Serial.print(F(","));
  #endif

  // now that all controls are updated, update the source.

  voices[0]->updateControl();
  voices[1]->updateControl();

  #ifndef ENABLE_MIDI_OUTPUT
  /*
  Serial.print(micros() - lastUpdateMicros);
  Serial.print(F(","));
  Serial.print(updateCounter % INTERFACE_UPDATE_DIVIDER_DIGITAL);
  Serial.print(F(","));
  Serial.print(updateCounter % INTERFACE_UPDATE_DIVIDER_ANALOG);
  Serial.print(F(","));
  Serial.print(sequenceUpdated);
  Serial.println();
  */
  #endif

  // do the display update last so that any latency is introduced after the notes are updated
  if (doDisplayUpdate)
  {
    updateDisplay();
  }

}



/*----------------------------------------------------------------------------------------------------------
 * updateLFOModulationDisplay
 * displays the current position of the 2 LFOs using 4 LEDs each
 *----------------------------------------------------------------------------------------------------------
 */
void updateLFOModulationDisplay()
{
  if (!firstTimeStart && settingDisplayTimer.ready())
  {
    // divide LFO value of 0-255 to range 0-3 by right-shift 6 bits, then right-shift 128 by that value to get the correct pixel bitfield
    // originally used floating point maths - very slow.
    ledDisplay.setRowPixels(LFO_TRACK_0_DISPLAY_ROW, (128 >> (voice0.getLFOValue() >> 6)) | (8 >> (voice1.getLFOValue() >> 6)));
    
    ledDisplay.refresh();
  }
}



/*----------------------------------------------------------------------------------------------------------
 * updateSequencer
 * updates sequencer
 * returns true if the sequencer advances a step
 *----------------------------------------------------------------------------------------------------------
 */
int updateSequencer()
{
  byte nextNote[MAX_SEQUENCER_TRACKS];
  uint16_t nextNoteLength;
  
  // if the sequencer is due to make a new step, 
  if (sequencer.update(false))
  {
    nextNoteLength  = sequencer.getNextNoteLength();

    for (uint8_t i=0; i<MAX_SEQUENCER_TRACKS; i++) 
    {
      nextNote[i] = sequencer.getCurrentNote(i);
     
      if (nextNote[i] > 0)
      {
        //todo: find way to extend param locks to channel 2?
        if (i==0)
        {
          getParameterLocks();
        }

        voices[i]->noteOn(nextNote[i], 255, nextNoteLength);

      }
    }
    #ifdef ENABLE_MIDI_OUTPUT
    //midiNoteOn(1,nextNote[0],127);
    if (nextNote[0])
    {
      Serial.write(0x90);
      Serial.write(nextNote[0]-24);
      Serial.write(0x45);
    }
    #else

    #endif


    return true;
  }
  else
  {
    return false;
  }

  
}



/*----------------------------------------------------------------------------------------------------------
 * outputSyncPulse
 * sends a digital signal to the output pin and sets the timer to pull it low after TIMER_SYNC_PULSE_OUTPUT_MILLIS
 *----------------------------------------------------------------------------------------------------------
 */
void outputSyncPulse()
{
  /*
  DEBUG only
  static uint32_t lastSyncOutTimeMicros;
  static uint32_t thisSyncOutTimeMicros;

  thisSyncOutTimeMicros = mozziMicros();
  Serial.print(F("lastSyncOutTimeMicros = "));
  Serial.println(thisSyncOutTimeMicros - lastSyncOutTimeMicros);
  lastSyncOutTimeMicros = thisSyncOutTimeMicros;
  */

  syncOutputTimer.start(TIMER_SYNC_PULSE_OUTPUT_MILLIS);
  digitalWrite(PIN_SYNC_OUT,  HIGH);
}


/*----------------------------------------------------------------------------------------------------------
 * getParameterLocks
 * updates source parameters based on stored modulation sequence
 * parameter locks are only available for first track only.
 *----------------------------------------------------------------------------------------------------------
 */
void getParameterLocks()
{
  uint16_t  thisParamLock;
  uint8_t   thisStep;
  int8_t    synthParamIndex;

  // parameters are recorded on the longest sequence but only applied to track 1 voice
  // this way if track 1 is 5 steps but track 2 is 16 steps, the automation will be 16 steps long
  if (sequencer.getSequenceLength(SEQUENCER_TRACK_1) > sequencer.getSequenceLength(SEQUENCER_TRACK_0))
  {
    thisStep = sequencer.getCurrentStep(SEQUENCER_TRACK_1);
  }
  else
  {
    thisStep = sequencer.getCurrentStep(SEQUENCER_TRACK_0);
  }

  for (uint8_t paramIndex = 0; paramIndex < MAX_PARAMETER_LOCKS; paramIndex++)
  {
    thisParamLock = sequencer.getParameterLock(paramIndex, SEQUENCER_TRACK_0, thisStep);
    
    if (thisParamLock != 0)
    {
      #ifndef ENABLE_MIDI_OUTPUT

      /*
      Serial.print(F("parameter lock for channel "));
      Serial.print(SEQUENCER_TRACK_0);
      Serial.print(F(" parameter "));
      Serial.print(paramIndex);
      Serial.print(F(" value "));
      Serial.println(thisParamLock);
      */
      #endif

      // set the flag for this input - last parameter was a lock
      bitsLastParamLock |= 1 << paramIndex;
    }
    else 
    {
      // if the last step was a parameter lock but this step doesn't have one, set the parameter lock to the current knob position
      if ((bitsLastParamLock >> paramIndex) & 1)
      {
        #ifndef ENABLE_MIDI_OUTPUT

        /*
        Serial.print(F("clearing last parameter lock for channel "));
        Serial.print(SEQUENCER_TRACK_0);
        Serial.print(F(" parameter "));
        Serial.print(paramIndex);
        Serial.print(F(" knob value "));
        Serial.println(iCurrentAnalogValue[getParameterLockControl(paramIndex)]);
        */
        #endif
        thisParamLock = iCurrentAnalogValue[getParameterLockControl(paramIndex)];
      }

      // reset the lock bitflag for this parameter
      bitsLastParamLock &= ~(1 << paramIndex);  

    }
    
    // if there is a parameter lock or we are recovering from a previous step parameter lock 
    if (thisParamLock != 0)
    {
      synthParamIndex = getParameterLockSynthParam(paramIndex);
      
      if (synthParamIndex == -2)
      {
        sequencer.setNextNoteLength(thisParamLock);
      }
      else if (synthParamIndex >= 0)
      {
        voices[SEQUENCER_TRACK_0]->setParam(synthParamIndex, thisParamLock);
      }
    }
    //}
  }

}



/*----------------------------------------------------------------------------------------------------------
 * setParameterLock
 * saves the given parameter value onto a modulation channel
 *----------------------------------------------------------------------------------------------------------
 */
inline void setParameterLock(int8_t paramChannel, uint16_t value)
{
  switch (motionRecordMode)
  {
    // 14/02/22: moved this here as is the most common case, assuming no branch prediction on arduion platforms
    case MOTION_RECORD_NONE:
        // do nothing 
        break;

    case MOTION_RECORD_REC:
        sequencer.setParameterLock(paramChannel, value);
        #ifndef ENABLE_MIDI_OUTPUT
        //Serial.println(F("setParameterLock(0)"));
        #endif
        break;

    case MOTION_RECORD_CLEAR:
        sequencer.clearAllParameterLocks(paramChannel);
        #ifndef ENABLE_MIDI_OUTPUT
        //Serial.println(F("Clear ParameterLock(0)"));
        #endif
        break;

  }
}



/*----------------------------------------------------------------------------------------------------------
 * getParameterLockChannel
 * returns the sequencer modulation channel for a given analog control index 
 * 
 * These are a bit of a kludge - would be better as a lookup table.
 *----------------------------------------------------------------------------------------------------------
 */
inline int8_t getParameterLockChannel(uint8_t analogControlIndex)
{
  switch(analogControlIndex)
  {
    case ANALOG_INPUT_MOD_AMOUNT:    return PARAM_LOCK_CHANNEL_0;       
    case ANALOG_INPUT_DECAY:         return PARAM_LOCK_CHANNEL_1;
    case ANALOG_INPUT_MOD_RATIO:     return PARAM_LOCK_CHANNEL_2;
    case ANALOG_INPUT_MOD_ENVELOPE1: return PARAM_LOCK_CHANNEL_3;
    case ANALOG_INPUT_MOD_ENVELOPE2: return PARAM_LOCK_CHANNEL_4;
    case ANALOG_INPUT_LFO:           return PARAM_LOCK_CHANNEL_5;
    default:  return -1;
  }
}


/*----------------------------------------------------------------------------------------------------------
 * getParameterLockControl
 * returns the analog control index for a given sequencer modulation channel 
 *----------------------------------------------------------------------------------------------------------
 */
inline int8_t getParameterLockControl(uint8_t paramChannelIndex)
{
  switch(paramChannelIndex)
  {
    case PARAM_LOCK_CHANNEL_0: return ANALOG_INPUT_MOD_AMOUNT;
    case PARAM_LOCK_CHANNEL_1: return ANALOG_INPUT_DECAY;
    case PARAM_LOCK_CHANNEL_2: return ANALOG_INPUT_MOD_RATIO;
    case PARAM_LOCK_CHANNEL_3: return ANALOG_INPUT_MOD_ENVELOPE1;
    case PARAM_LOCK_CHANNEL_4: return ANALOG_INPUT_MOD_ENVELOPE2;
    case PARAM_LOCK_CHANNEL_5: return ANALOG_INPUT_LFO;
    default:  return -1;
  }
}


/*----------------------------------------------------------------------------------------------------------
 * getParameterLockSynthParam
 * returns the sytnh parameter for a given sequencer modulation channel 
 *----------------------------------------------------------------------------------------------------------
 */
inline int8_t getParameterLockSynthParam(uint8_t paramChannelIndex)
{
  switch(paramChannelIndex)
  {
    case PARAM_LOCK_CHANNEL_0: return SYNTH_PARAMETER_MOD_AMOUNT;
    case PARAM_LOCK_CHANNEL_1: return SYNTH_PARAMETER_NOTE_DECAY;
    case PARAM_LOCK_CHANNEL_2: return SYNTH_PARAMETER_MOD_RATIO;
    case PARAM_LOCK_CHANNEL_3: return SYNTH_PARAMETER_ENVELOPE_DECAY;
    case PARAM_LOCK_CHANNEL_4: return SYNTH_PARAMETER_ENVELOPE_ATTACK;
    case PARAM_LOCK_CHANNEL_5: return SYNTH_PARAMETER_MOD_AMOUNT_LFODEPTH;
    default:  return SYNTH_PARAMETER_UNKNOWN;
  }
}






/*----------------------------------------------------------------------------------------------------------
 * updateSyncTrigger
 * check for incoming sync trigger and update sequencer
 * also check to see if output sync trigger needs to be pulled low
 *----------------------------------------------------------------------------------------------------------
 */
void updateSyncTrigger()
{
  iTrigger = digitalRead(PIN_SYNC_IN);   // read the sync pin
  if (iTrigger != iLastTrigger)
  {
    digitalWrite(PIN_SYNC_OUT, iTrigger);
    
    //trigger note on or off
    if (iTrigger == HIGH)
    {
      #ifndef ENABLE_MIDI_OUTPUT
      //Serial.println("sync!");
      #endif
      sequencer.syncPulse(SYNC_STEPS_PER_PULSE);
    }

    iLastTrigger = iTrigger;
  }

  // check to see if the output sync pulse needs to be pulled low
  if (syncOutputTimer.ready())
  {
    digitalWrite(PIN_SYNC_OUT, LOW);
  }
  
}


/*----------------------------------------------------------------------------------------------------------
 * getLastButtonState
 * returns the last state for the given button 
 * uses a bitfield to compress 
 *----------------------------------------------------------------------------------------------------------
 */
inline uint8_t getLastButtonState(uint8_t buttonIndex)
{
  return (bitsLastButton >> buttonIndex) & 1;
}
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
void loop() 
{
  //required for Mozzi
  audioHook();
}

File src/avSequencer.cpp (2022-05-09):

/*----------------------------------------------------------------------------------------------------------
 * avSequencer.cpp
 * 
 * Implements a generative sequencer with multiple generative algorithms, musical scale quantisation,
 * variable sequence length (up to 16 steps) and multiple parameter-lock (motion-sequencing) channels
 * 
 * (C) 2021-2022 Meebleeps
*-----------------------------------------------------------------------------------------------------------
*/
#include <mozzi_rand.h>
#include <MozziGuts.h>

#include "Arduino.h"
#include "avSequencer.h"


/*----------------------------------------------------------------------------------------------------------
 * MutatingSequencer::MutatingSequencer()
 * initialises the sequencer
 *----------------------------------------------------------------------------------------------------------
 */
MutatingSequencer::MutatingSequencer()
{
  running             = false;
  mutationAlgorithm   = MUTATE_ALGO_DEFAULT;

  // initialise sequence
  for (uint8_t i = 0; i < MAX_SEQUENCE_LENGTH; i++)
  {
    notes[i] = 0;
  }
  
  for (uint8_t i = 0; i < MAX_SCALE_LENGTH; i++)
  {
    scaleNotes[i] = 0;
  }

  for (uint8_t i = 0; i < MAX_SEQUENCE_LENGTH; i++)
  {
    for (uint8_t m = 0; m < MAX_PARAMETER_LOCKS; m++)
    {
      parameterLocks[m][i] = 0;
    }
  }

  currentStep         = 0;  
  retrigStep          = 0;     
  retrigState         = false;                        
  tonicNote           = 9;   // default to A
  octave              = 1;                           
  mutationProbability = 0;
  noteProbability      = 70;
  tonicProbability    = 30;
  sequenceLength      = 16;
  bpm                 = 130;
  currentNote         = tonicNote;
  nextStepNoteLength  = 80;
  octaveSpread        = 3;  
  scaleNoteCount      = 7;

  // deleted this to allow for different pulse steps defined by the UI layer
  //syncPulseSteps        = 2;      // standard 2 steps per sync pulse as per volca
  syncPulseClockDivide  = 1;      // divide the clock by this many steps
  
  nextStepTimeMillis  = (15000 / bpm); // 16th note length for given BPM
  
  lastSyncPulseTimeMicros = 0;
  
  initialiseScale(SCALEMODE_PENTA);
  newSequence(sequenceLength);

  _debugOutput        = true;
  printParameters();
}



/*----------------------------------------------------------------------------------------------------------
 * MutatingSequencer::start()
 * starts the sequencer at step 0
 *----------------------------------------------------------------------------------------------------------
 */
void MutatingSequencer::start()
{
  #ifndef ENABLE_MIDI_OUTPUT
  Serial.println(F("Sequencer.Start()"));
  #endif
  running             = true;
  ignoreNextSyncPulse = true;
  //nextStep(true);
}




/*----------------------------------------------------------------------------------------------------------
 * MutatingSequencer::stop()
 * stops the sequencer
 *----------------------------------------------------------------------------------------------------------
 */
void MutatingSequencer::stop()
{
  #ifndef ENABLE_MIDI_OUTPUT
  Serial.println(F("Sequencer.Stop()"));
  #endif
  running = false;
}


/*----------------------------------------------------------------------------------------------------------
 * MutatingSequencer::toggleStart()
 * starts the sequencer if it is stopped, otherwise stops it
 *----------------------------------------------------------------------------------------------------------
 */
void MutatingSequencer::toggleStart()
{
  if (!running)
  {
    start();
  }
  else
  {
    stop();  
  }
}



/*----------------------------------------------------------------------------------------------------------
 * MutatingSequencer::setScale()
 * sets the scale and generates a new sequence according to the new scale
 *----------------------------------------------------------------------------------------------------------
 */
 void MutatingSequencer::setScale(uint8_t scaleMode)
{
  initialiseScale(scaleMode);
  newSequence(sequenceLength);
  #ifndef ENABLE_MIDI_OUTPUT
  Serial.print(F("NEW SCALE: "));
  Serial.println(scaleMode);
  #endif
}


/*----------------------------------------------------------------------------------------------------------
 * MutatingSequencer::getScale()
 * returns the current scale mode
 *----------------------------------------------------------------------------------------------------------
 */
 uint8_t MutatingSequencer::getScale()
{
  return currentScaleMode;
}


/*----------------------------------------------------------------------------------------------------------
 * MutatingSequencer::getAlgorithm()
 * returns the current mutation algorithm
 *----------------------------------------------------------------------------------------------------------
 */
uint8_t MutatingSequencer::getAlgorithm()
{
  return mutationAlgorithm;
}


/*----------------------------------------------------------------------------------------------------------
 * MutatingSequencer::setAlgorithm()
 * sets the current mutation algorithm
 *----------------------------------------------------------------------------------------------------------
 */
void MutatingSequencer::setAlgorithm(uint8_t newValue)
{
  mutationAlgorithm = newValue % MAX_MUTATE_ALGO_COUNT;
}

/*----------------------------------------------------------------------------------------------------------
 * MutatingSequencer::incrAlgorithm()
 * moves to the next algorithm
 *----------------------------------------------------------------------------------------------------------
 */
void MutatingSequencer::nextAlgorithm()
{
  mutationAlgorithm = (mutationAlgorithm + 1) % MAX_MUTATE_ALGO_COUNT;
  #ifndef ENABLE_MIDI_OUTPUT
  Serial.print(F("New Algorithm = "));
  Serial.println(mutationAlgorithm);
  #endif
}




/*----------------------------------------------------------------------------------------------------------
 * MutatingSequencer::getCurrentNote()
 * gets the note value for the current step
 *----------------------------------------------------------------------------------------------------------
 */
byte MutatingSequencer::getCurrentNote()
{
  if (!retrigState)
  {
    return notes[currentStep];
  }
  else
  {
    return notes[retrigStep];
  }
}


/*----------------------------------------------------------------------------------------------------------
 * MutatingSequencer::getCurrentStep()
 * gets  the current playing step
 *----------------------------------------------------------------------------------------------------------
 */
byte MutatingSequencer::getCurrentStep()
{
  if(!retrigState)
  {
    return currentStep;
  }
  else
  {
    return retrigStep;
  }
  
}
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

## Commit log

2022-02-06 Added track 1 octave-shift function. Updated readme
2022-02-06 Added track 1 octave offset function
2022-02-08 Added schematics as image and Fritzing file
    [MeeBleeps Freaq Schematic 08022022.fzz]
2022-02-09 Fixed bug in LedMatrix.h (#ifndef)
    [LedMatrix.h]
2022-02-10 Added build-note re normally-closed switches
2022-02-10 Added code to support normally-open switches
2022-02-10 Added support for normally-open switches
2022-02-13 Added faceplate & enclosure
    [Mutant-Freaq Synth Box v1.0.dxf]
2022-02-19 normally-closed switches & Arduino IDE notes
2022-03-26 Fixed schematic pinout for MIDI output
    [MeeBleeps Freaq Schematic 26032022.fzz]
2022-04-17 Added 3D-printed enclosure files
2022-05-09 Added compile-size & button-type options
2022-06-29 More useful Readme info Pins of the controls, build issues, LED control board
2024-10-24 Updated to clarify Meebleeps/Wirehead/Meeblip
